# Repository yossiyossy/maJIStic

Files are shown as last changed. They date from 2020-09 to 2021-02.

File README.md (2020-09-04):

# maJIStic
Mac標準のキーボードの配列を意識した、日本語配列のキーボード

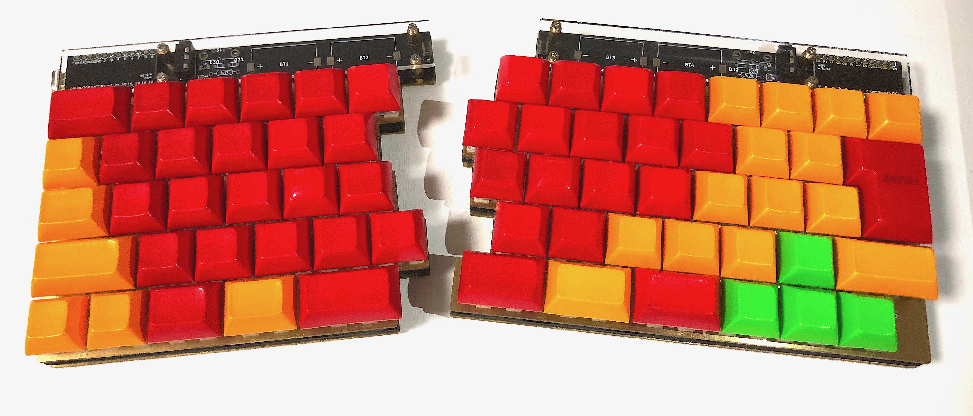
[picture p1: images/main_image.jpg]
main_image

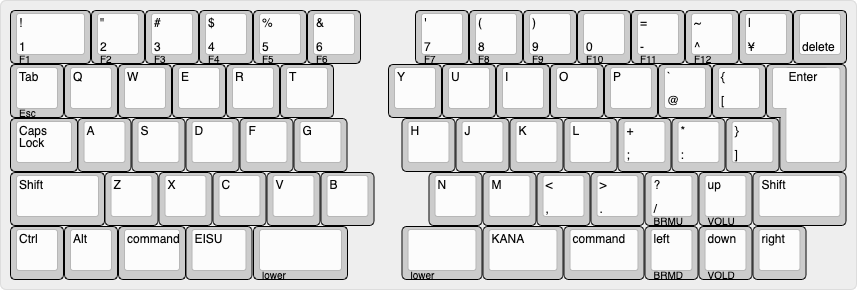
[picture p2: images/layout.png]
keyboard-layout


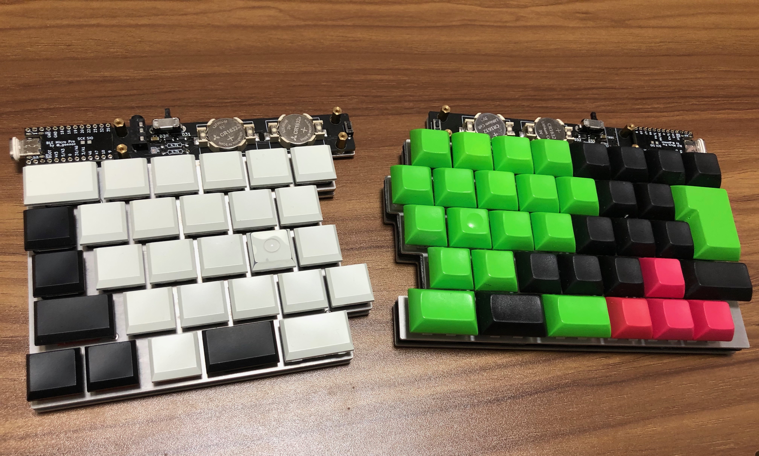
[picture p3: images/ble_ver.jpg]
ble_ver


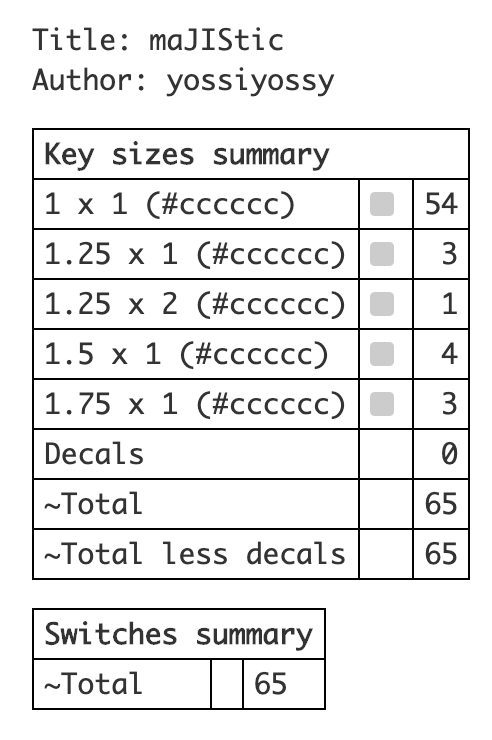
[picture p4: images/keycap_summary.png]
keycap_summary


[ビルドガイド](/docs/buildguide.md)

[特徴](/docs/feature.md)

# 買えるところ
- [booth](https://yossiyossy.booth.pm/items/2325429)

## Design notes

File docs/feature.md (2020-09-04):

# maJISticの特徴
maJISticには以下のような特徴があります
- JIS配列の左右分離型キーボード
- magic keyboard っぽい配列(1が1.5u, tabが1u, 十字キーがある)
- ソケットに対応(組み立て後にもスイッチを交換できる)
- MX, chocの両方に同時に対応させることができる
- ble micro proを使用した完全無線化に対応

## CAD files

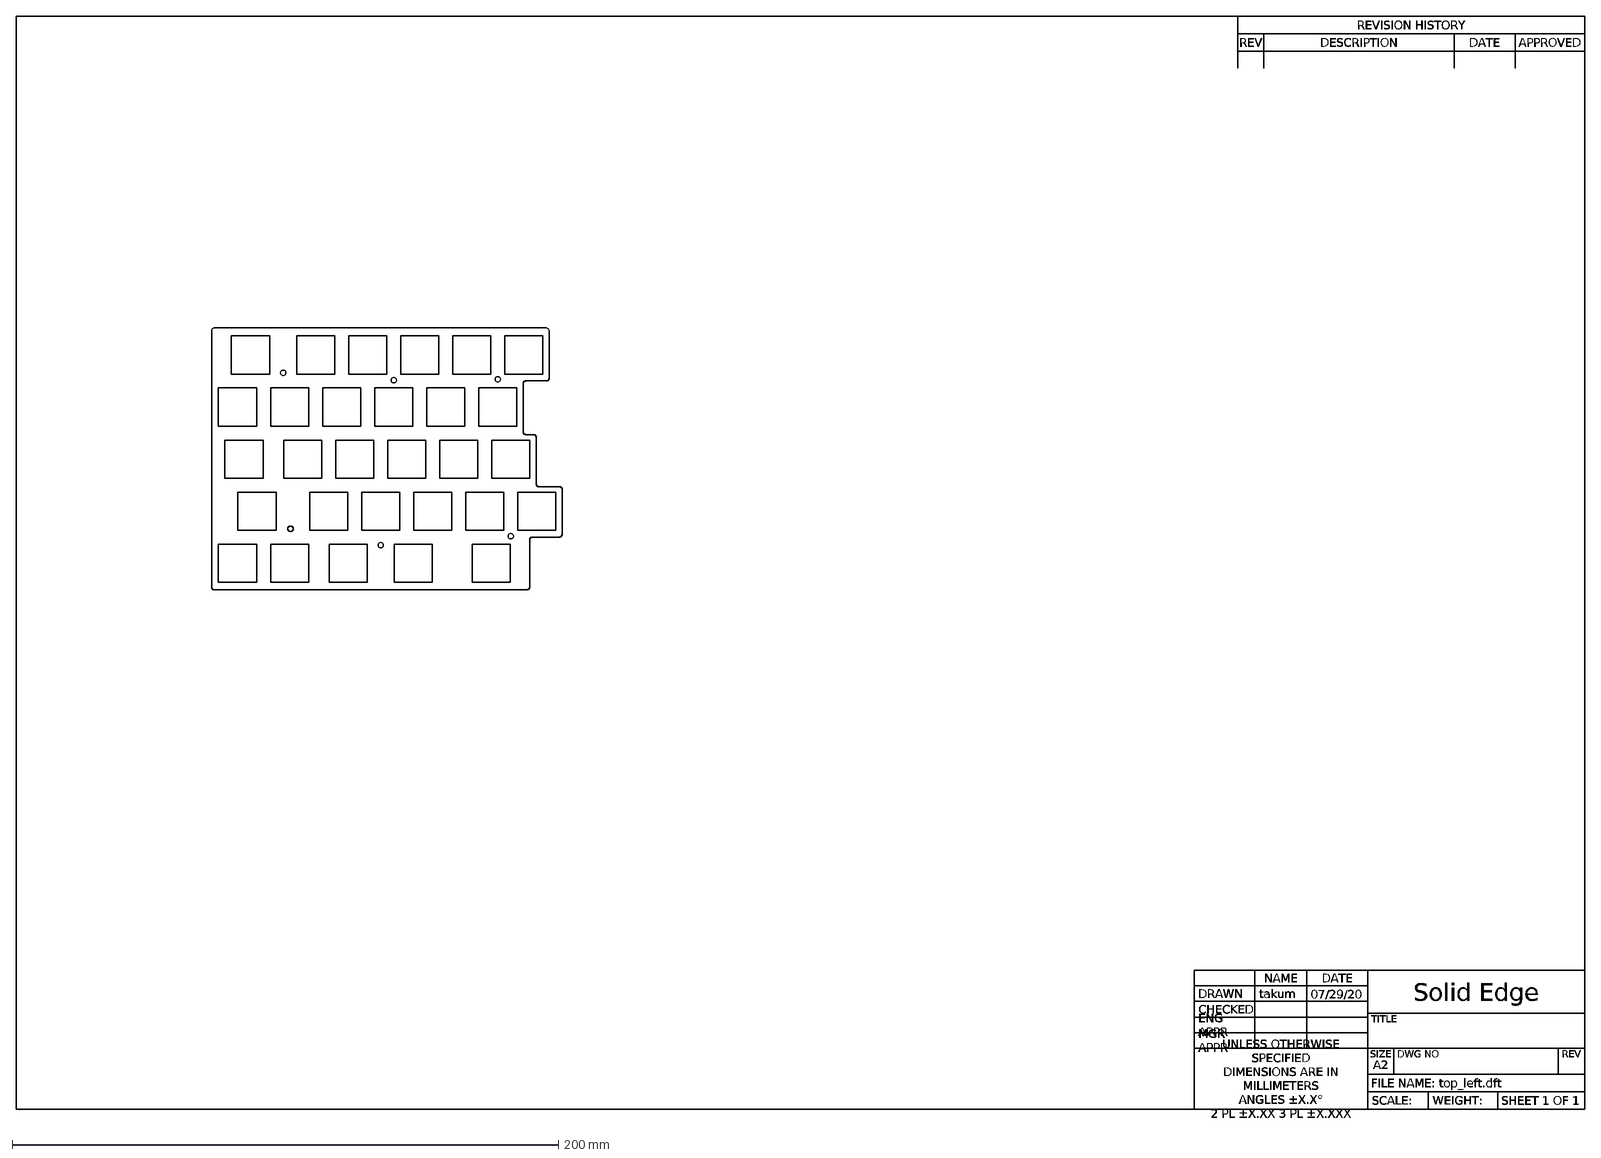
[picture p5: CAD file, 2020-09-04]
case/dxf/top_left.dxf
DRAWN
CHECKED
ENG APPR
MGR APPR
UNLESS OTHERWISE SPECIFIED DIMENSIONS ARE IN MILLIMETERS ANGLES ±X.X° 2 PL ±X.XX 3 PL ±X.XXX
NAME
takum
DATE
07/29/20
Solid Edge
TITLE
SIZE
A2
DWG NO
REV
FILE NAME: top_left.dft
SCALE:
WEIGHT:
SHEET 1 OF 1
REVISION HISTORY
DESCRIPTION
APPROVED

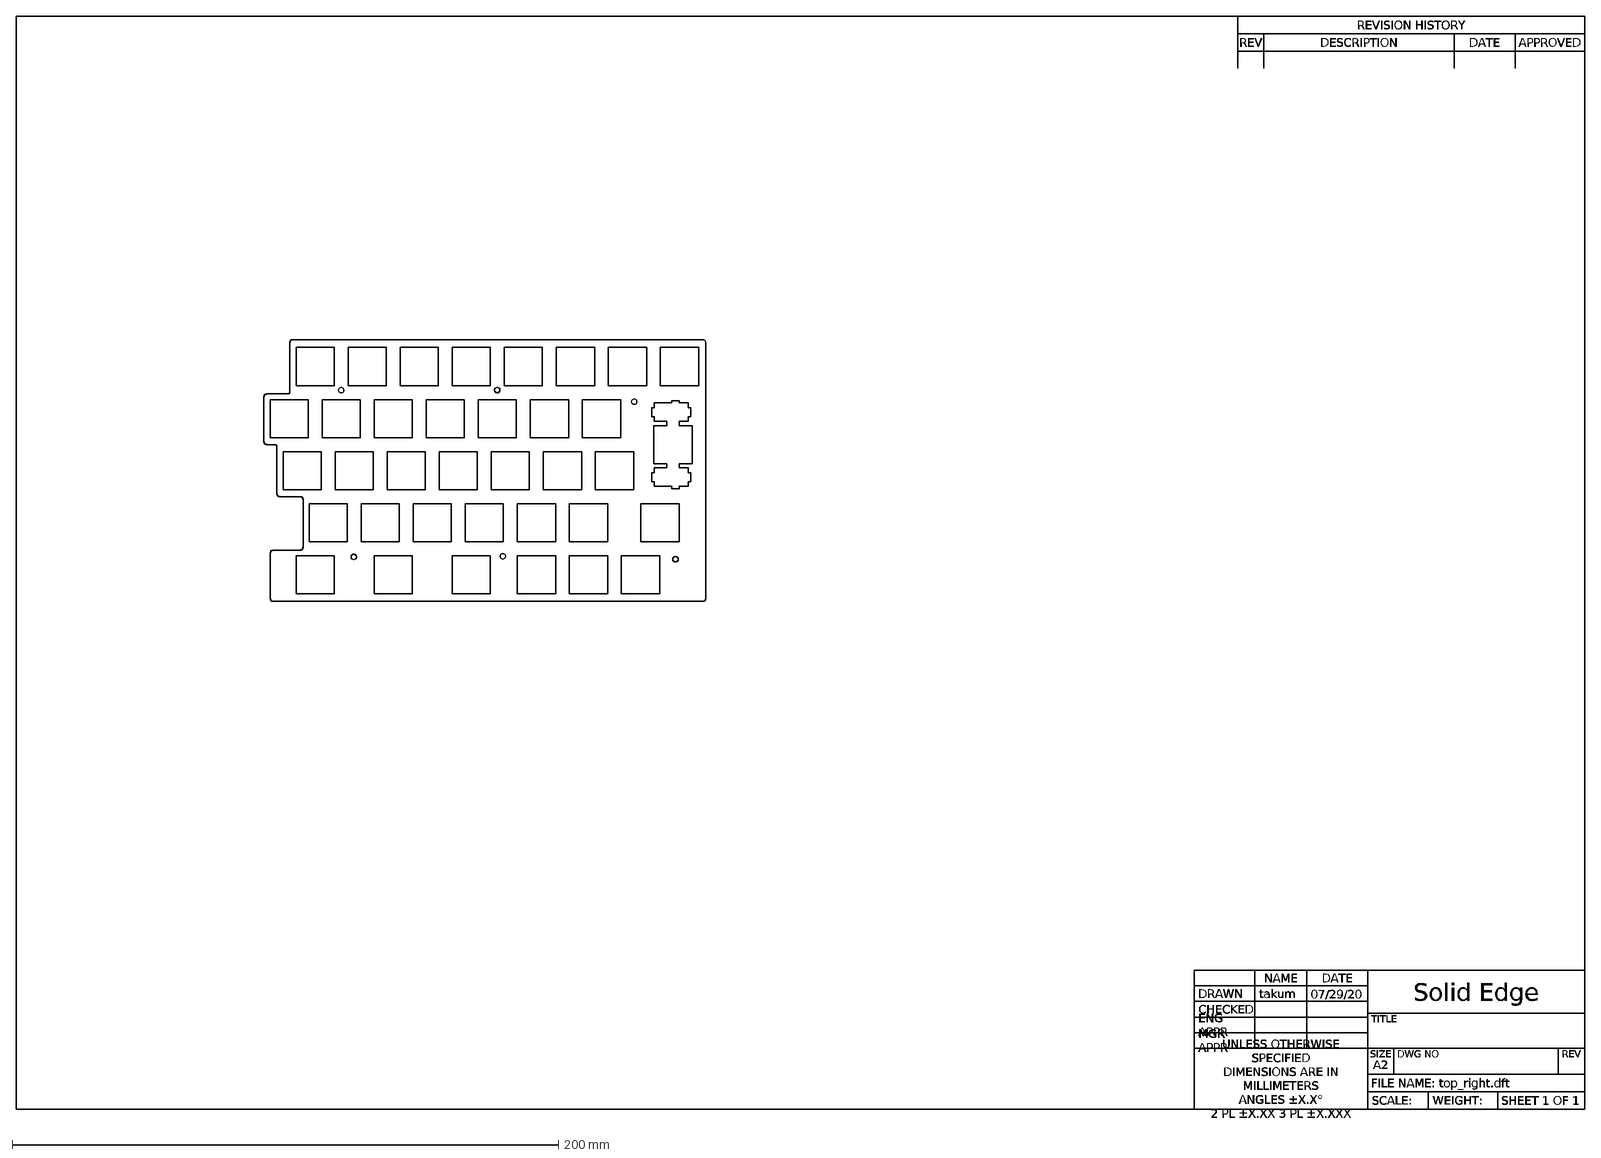
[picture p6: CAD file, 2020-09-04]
case/dxf/top_right.dxf
DRAWN
CHECKED
ENG APPR
MGR APPR
UNLESS OTHERWISE SPECIFIED DIMENSIONS ARE IN MILLIMETERS ANGLES ±X.X° 2 PL ±X.XX 3 PL ±X.XXX
NAME
takum
DATE
07/29/20
Solid Edge
TITLE
SIZE
A2
DWG NO
REV
FILE NAME: top_right.dft
SCALE:
WEIGHT:
SHEET 1 OF 1
REVISION HISTORY
DESCRIPTION
APPROVED

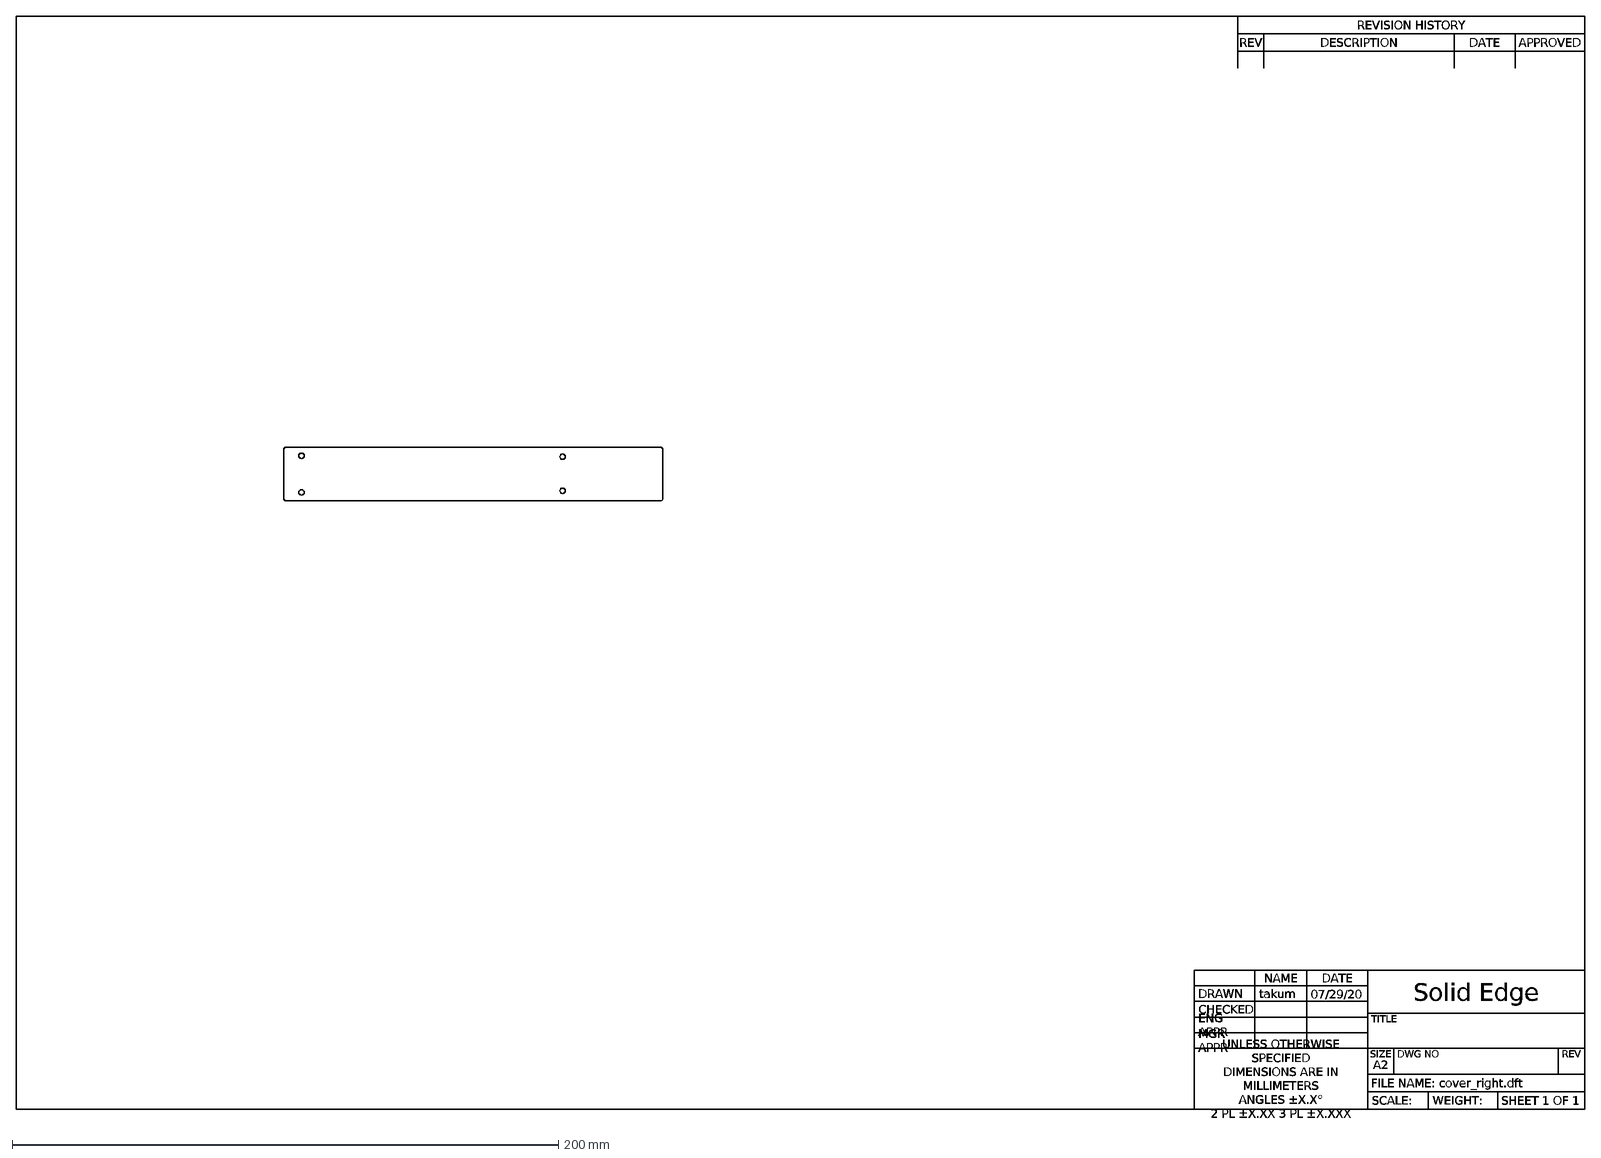
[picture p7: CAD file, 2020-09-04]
case/dxf/cover_right.dxf
DRAWN
CHECKED
ENG APPR
MGR APPR
UNLESS OTHERWISE SPECIFIED DIMENSIONS ARE IN MILLIMETERS ANGLES ±X.X° 2 PL ±X.XX 3 PL ±X.XXX
NAME
takum
DATE
07/29/20
Solid Edge
TITLE
SIZE
A2
DWG NO
REV
FILE NAME: cover_right.dft
SCALE:
WEIGHT:
SHEET 1 OF 1
REVISION HISTORY
DESCRIPTION
APPROVED

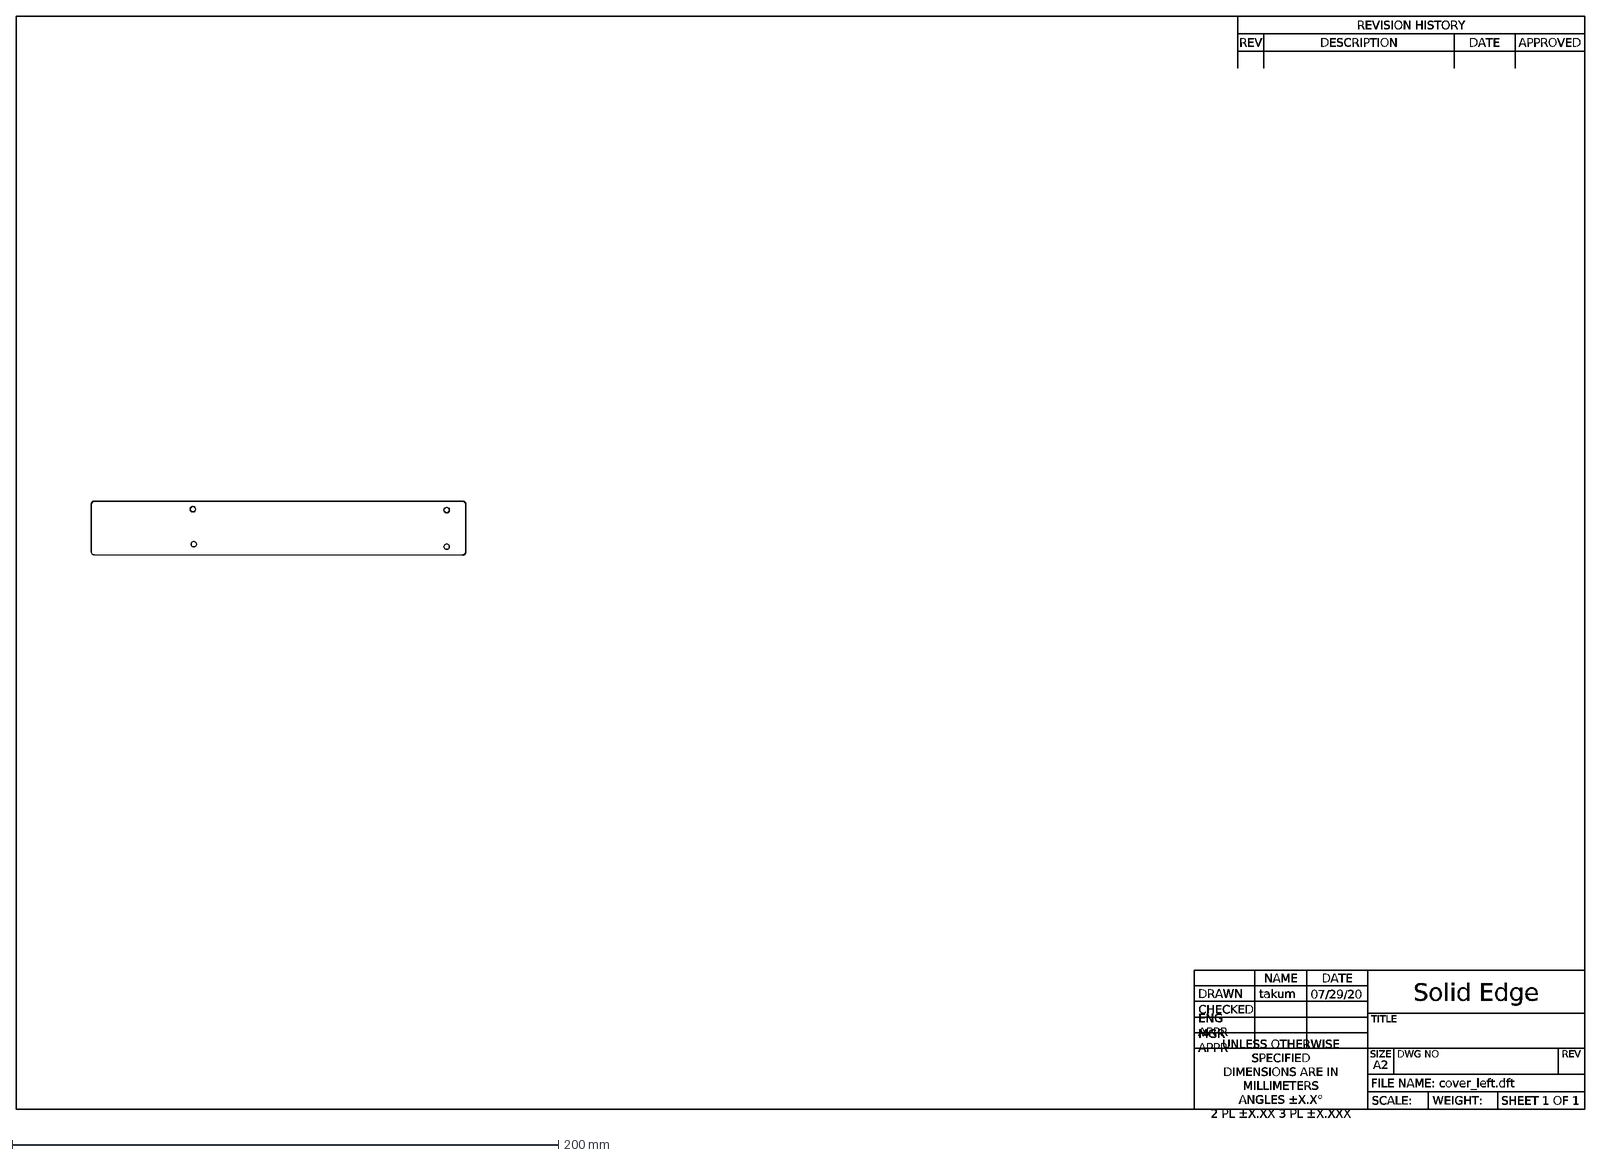
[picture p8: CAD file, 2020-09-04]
case/dxf/cover_left.dxf
DRAWN
CHECKED
ENG APPR
MGR APPR
UNLESS OTHERWISE SPECIFIED DIMENSIONS ARE IN MILLIMETERS ANGLES ±X.X° 2 PL ±X.XX 3 PL ±X.XXX
NAME
takum
DATE
07/29/20
Solid Edge
TITLE
SIZE
A2
DWG NO
REV
FILE NAME: cover_left.dft
SCALE:
WEIGHT:
SHEET 1 OF 1
REVISION HISTORY
DESCRIPTION
APPROVED

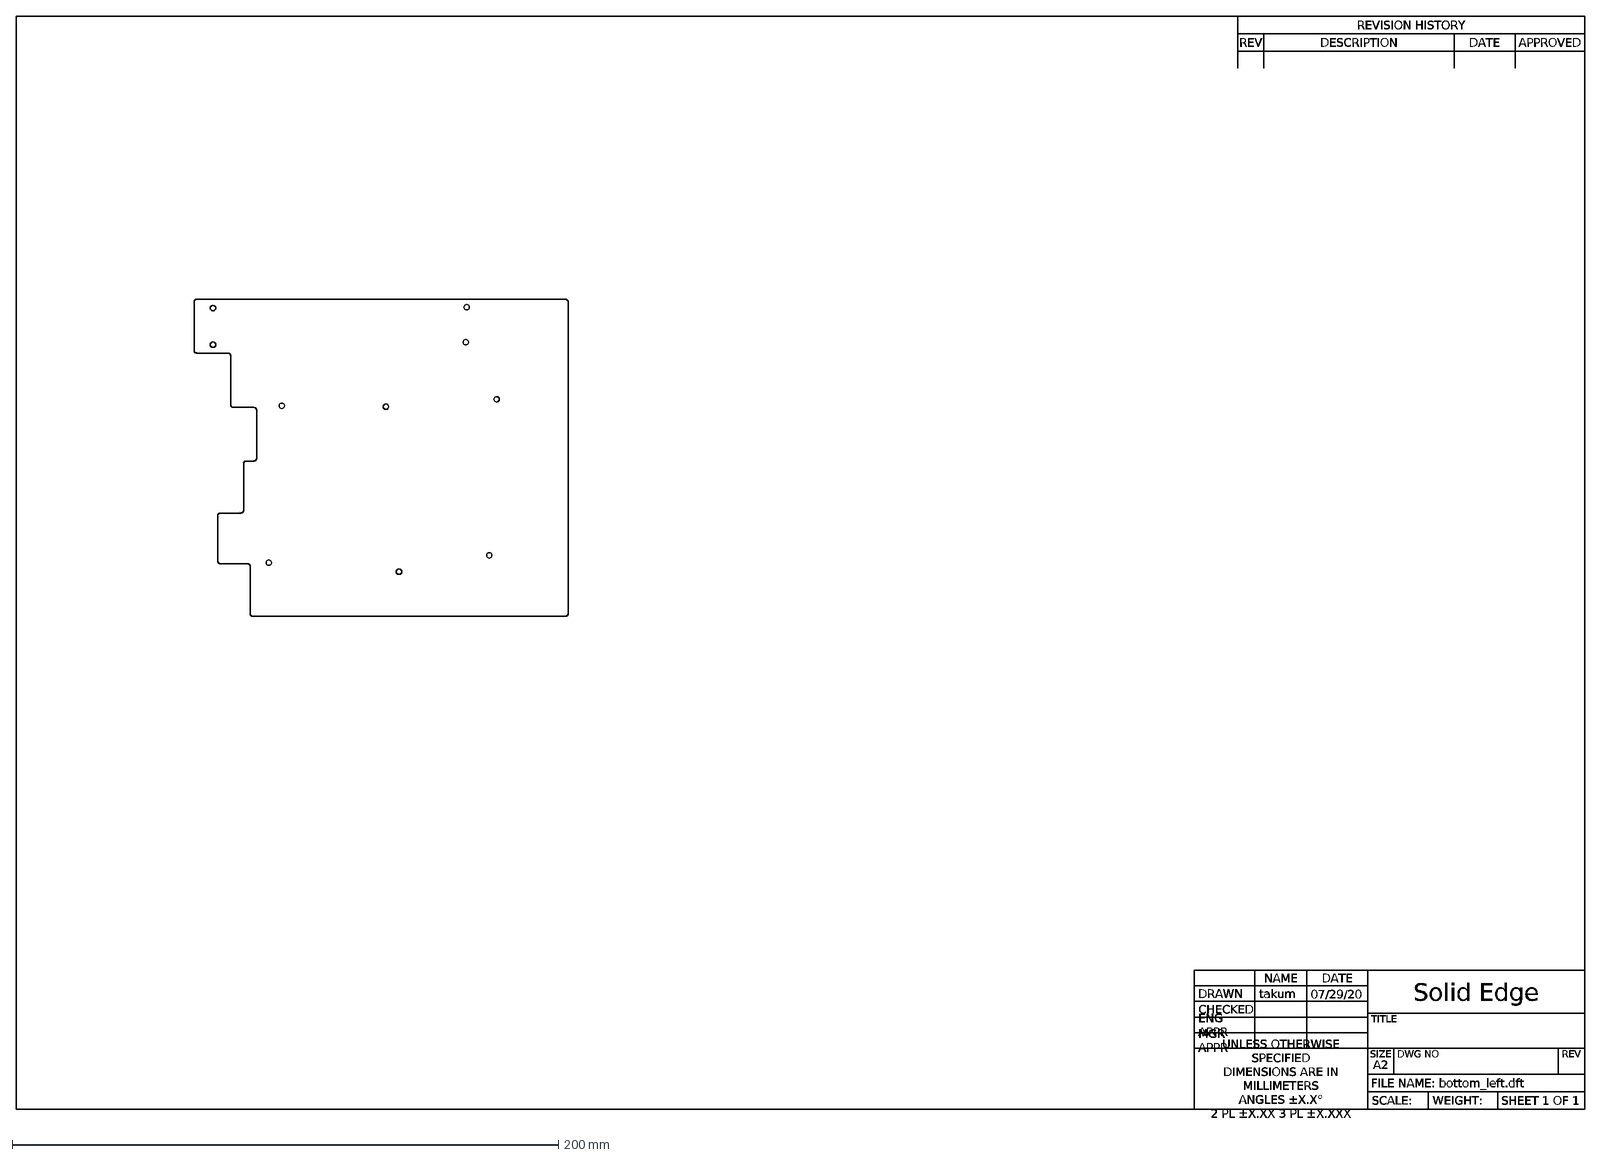
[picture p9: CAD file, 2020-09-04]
case/dxf/bottom_left.dxf
DRAWN
CHECKED
ENG APPR
MGR APPR
UNLESS OTHERWISE SPECIFIED DIMENSIONS ARE IN MILLIMETERS ANGLES ±X.X° 2 PL ±X.XX 3 PL ±X.XXX
NAME
takum
DATE
07/29/20
Solid Edge
TITLE
SIZE
A2
DWG NO
REV
FILE NAME: bottom_left.dft
SCALE:
WEIGHT:
SHEET 1 OF 1
REVISION HISTORY
DESCRIPTION
APPROVED

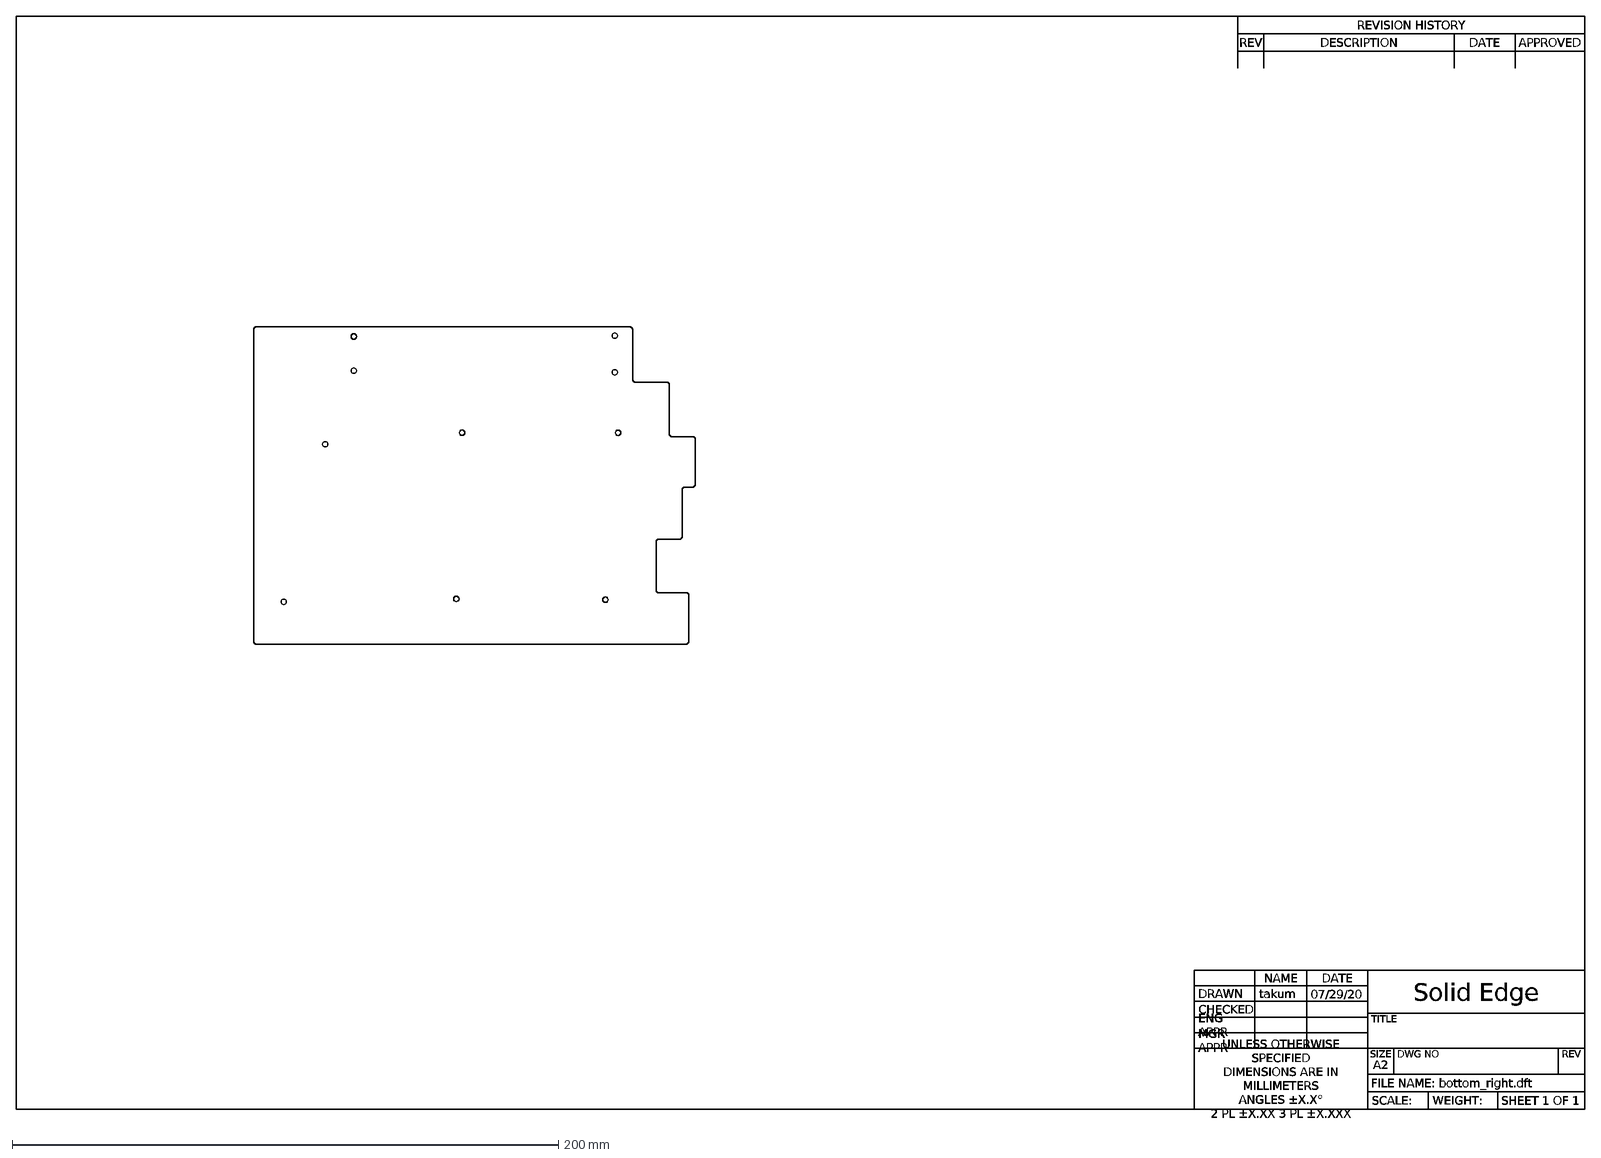
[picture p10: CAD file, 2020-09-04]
case/dxf/bottom_right.dxf
DRAWN
CHECKED
ENG APPR
MGR APPR
UNLESS OTHERWISE SPECIFIED DIMENSIONS ARE IN MILLIMETERS ANGLES ±X.X° 2 PL ±X.XX 3 PL ±X.XXX
NAME
takum
DATE
07/29/20
Solid Edge
TITLE
SIZE
A2
DWG NO
REV
FILE NAME: bottom_right.dft
SCALE:
WEIGHT:
SHEET 1 OF 1
REVISION HISTORY
DESCRIPTION
APPROVED

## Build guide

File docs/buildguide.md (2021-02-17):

# maJIStic ビルドガイド

## 部品

### 完成に必要な部品

#### よっしーのお店で買えるもの
| 名前 | 数 | 入っているセット | 備考 |
| :---- | :---- | :--- | :--- |
| PCB | 1枚 | 基板+基本パーツセット | |
| ダイオード (1N4148W) | 65個  | 基板+基本パーツセット | セットには予備として少し多めに入っています |
| TRRSジャック (MJ-4PP-9) | 2個 | 基板+基本パーツセット | |
| タクトスイッチ | 2個 | 基板+基本パーツセット | |
| ---- | ----  | --- | --- |
| スイッチ用PCBソケット(MX用) | 65個  | MX用ソケット類セット | |
| M2スペーサー 7.5mm | 12個  | MX用ソケット類セット | |
| M2ネジ 5mm | 24個  | MX用ソケット類セット | |
| ---- | ----  | --- | --- |
| スイッチ用PCBソケット(kailh choc ロープロファイル用) | 65個  | choc用ソケット類セット | |
| M2スペーサー 4mm | 12個  | choc用ソケット類セット | |
| M2ネジ 3mm | 24個  | choc用ソケット類セット | |
| ---- | ----  | --- | --- |
| トッププレート (アクリル/ アルミ/ ステンレス/ 真鍮 のいずれか) | 1組 | トッププレート | |
| ---- | ----  | --- | --- |
| ボトムプレート (アクリル/ アルミ/ ステンレス/ 真鍮 のいずれか) | 1組 | ボトムプレート | |
| ゴム足 | 8個 | ボトムプレート | |
| ---- | ----  | --- | --- |
| pro micro 保護カバー (アクリル) | 1組 | pro microカバー(アクリル) | |
| M2スペーサー 11mm | 8個 | pro microカバー(アクリル) | |
| M2ネジ 5mm | 16個  | pro microカバー(アクリル) | |

#### 他のところで買う必要のある部品
| 名前 | 数 | 備考 |
| :---- | :---- | :--- |
| Pro Micro | 2個 | |
| スプリングピンヘッダ 12P | 4個 | 通常のピンヘッダでも可 |
| 3.5mmオーディオケーブル  | 1本 | 左右のキーボード接続用 |
| micro USBケーブル | 1本 | PCとの接続用 |
| キースイッチ | 65個  | KalihロープロファイルあるいはMX互換 |
| キーキャップ | 65個  | キースイッチと互換があるもの |

### 完全無線化に必要な部品

#### よっしーのお店で買えるもの
| 名前 | 数 | 入っているセット | 備考 |
| :---- | :---- | :--- | :--- |
| コイン電池ホルダー | 4個 | 無線対応パーツセット | 注1  |
| スライドスイッチ | 2個 | 無線対応パーツセット | 注1  |
| コンデンサ | 2個 | 無線対応パーツセット | 注1  |
| ショットキーバリアダイオード | 4個 | 無線対応パーツセット | 注1  |

注1: セット1つには片手分の部品しか入っていません。完全無線化する場合はセットを2つ購入していただく必要があります。

#### 他のところで買う必要のある部品
| 名前 | 数 | 備考 |
| :---- | :---- | :--- |
| BLE Micro Pro | 2個 | Pro Microと置き換えて使用します |
| スプリングピンヘッダ 13P | 4個 | 通常のピンヘッダでも可 |
| 1632型コイン電池 | 4個 | |
| ポリウレタン銅線 | | 無線化時に短絡させる必要のある箇所を繋ぐのに使用します |

## 必要な道具

| 名前 | 備考 |
| :---- | :---- |
| はんだごて | |
| ハンダ | 0.8mm程度のものを推奨 |
| ピンセット | 表面実装部品の半田付けに使用 |

## 組み立て方

以降は左手分だけの説明を書きます。
右手分は左手分と同様に作業してください。

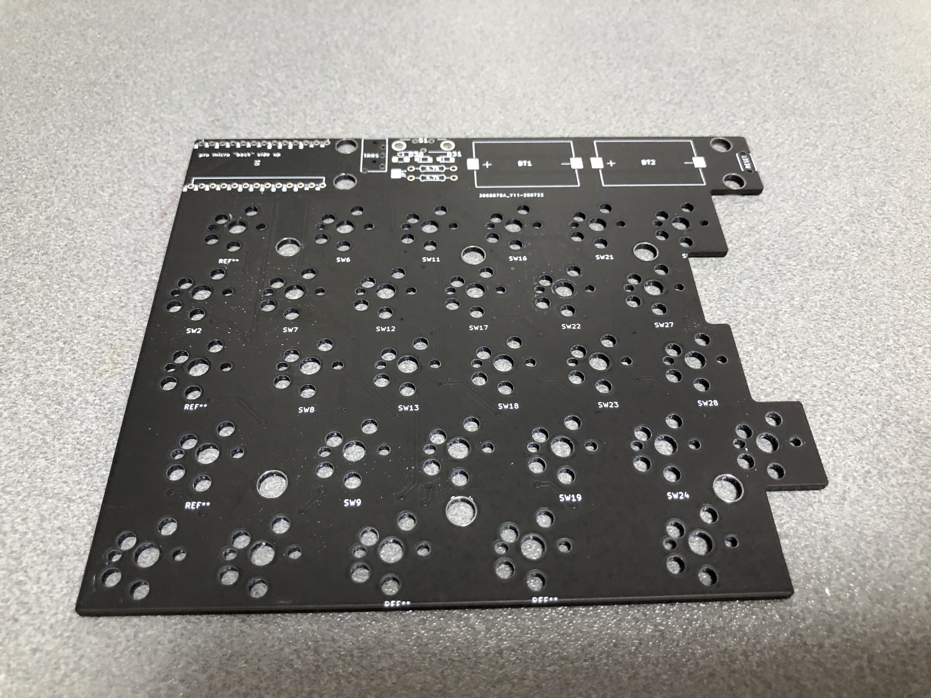
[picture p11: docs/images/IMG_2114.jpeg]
左手分のPCB


__一度全ての工程を読み、理解してから作業を進めることをお勧めします。__

### クリアラッカーの散布 (金属製ケースの場合)
~~maJISticの金属製ケースは、表面に特殊な処理をを行っておりません。~~
~~そのため、手汗などが付着するとくすみの原因になってしまいます。~~

~~事前に以下のようなクリアラッカー等で表面を保護することをおすすめします。~~

金属製ケースを製造していただいた切断堂様にて、クリアコートをしていただくようになったため、
今後発送する商品に関しては、特に下準備は必要なくなりました。(2021/02追記)

### PCBの準備 (部分無線化する場合)
オプションの**LPME-IOを使用した部分無線化を行う場合のみ**、以下の処理が必要です(左右両方の基盤に対して行う必要があります)
- カッターなどで以下のジャンパを切断する。
- 以下の箇所をポリウレタン銅線などでショートさせる

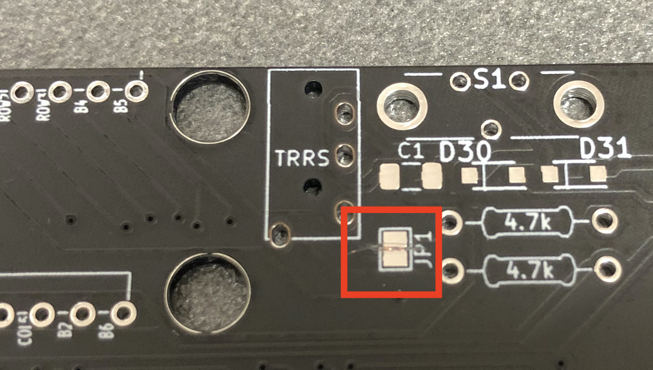
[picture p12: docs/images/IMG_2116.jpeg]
切るジャンパの画像


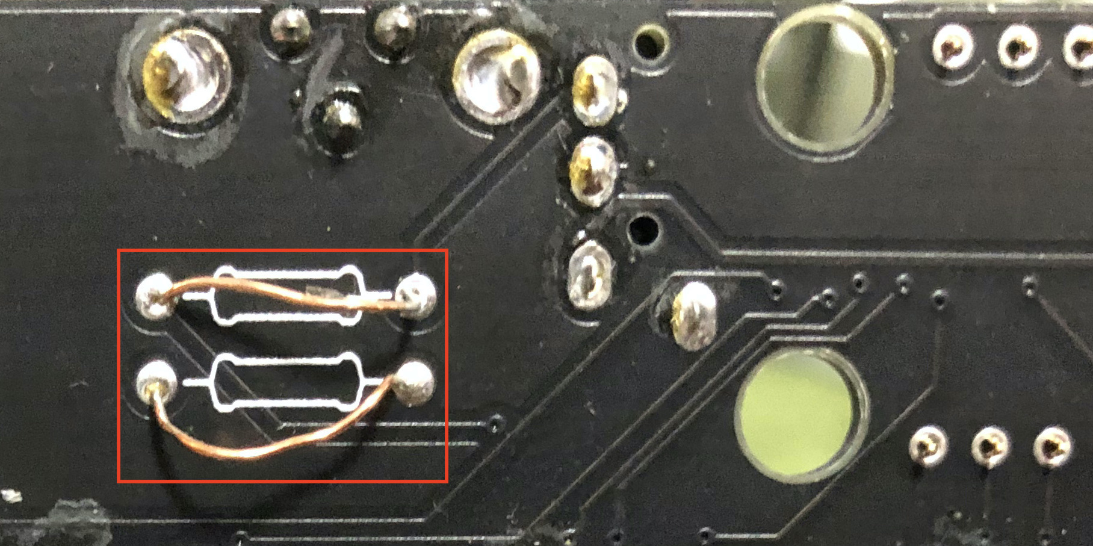
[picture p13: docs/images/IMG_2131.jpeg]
繋いだ画像


### パーツ実装

#### 無線化用パーツ
完全無線化する場合は左右両方に、部分無線化する場合は左手側に、無線化用パーツを取り付けます。

無線化に用いる部品は、それぞれがかなり小さいため、先に取り付けることをおすすめします。
特にTRRSジャックをつけた後に実装するのはかなり難しいため(体験談)、遅くともそこまでに取り付けてください。

コンデンサは向きがありませんが、ショットキーバリアダイオードは向きがあります。
かなりわかりにくかとは思いますが、シルクを見て取り付けてください。

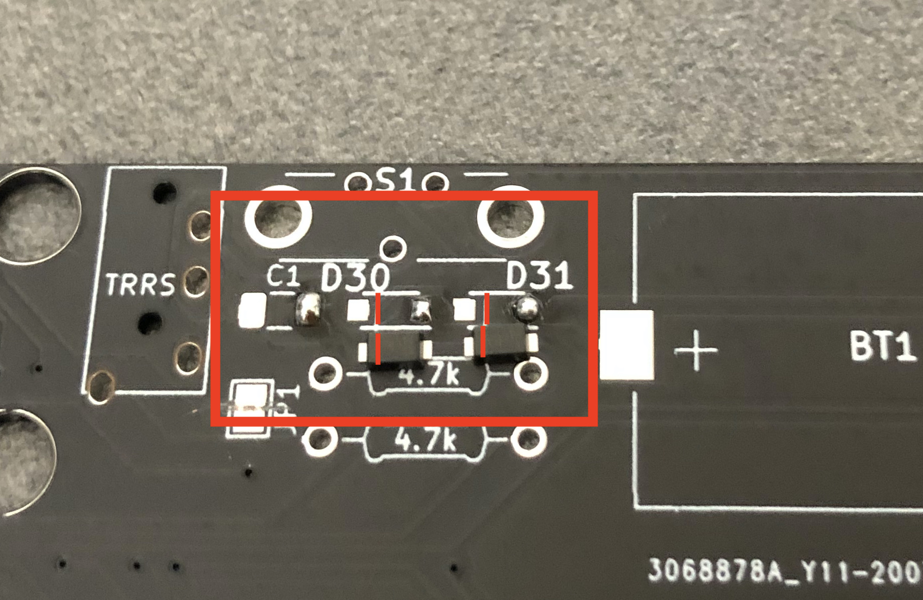
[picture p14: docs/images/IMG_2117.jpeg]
ショットキーバリアダイオードの付け方の画像


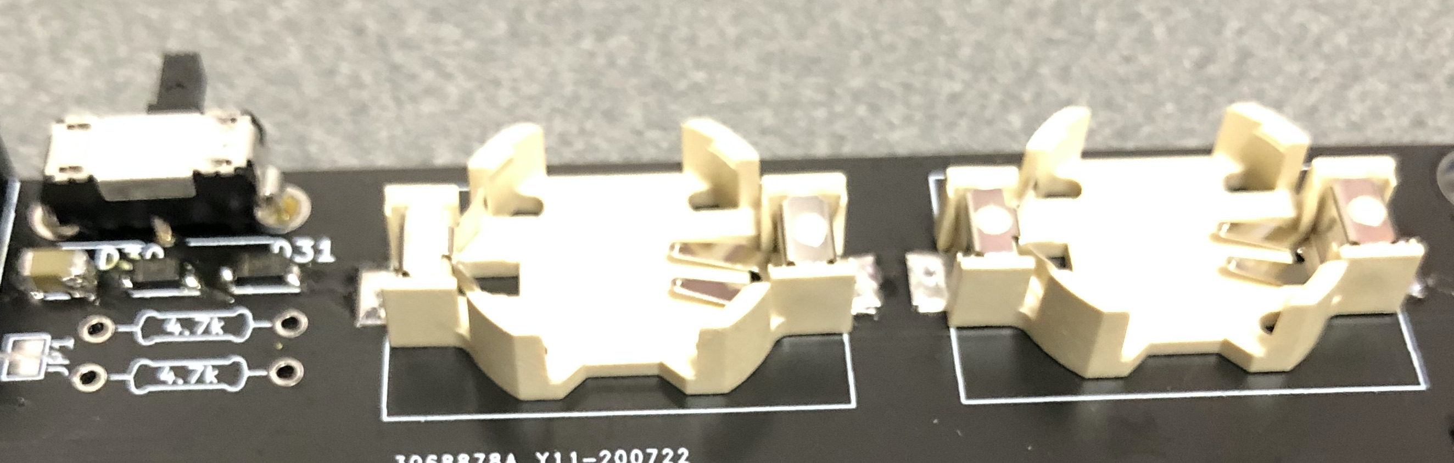
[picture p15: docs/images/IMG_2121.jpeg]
無線化用パーツを取り付けた姿の画像


#### ダイオード

ダイオードには向きがあるので注意してください。
シルクが見えなくなっているところがありますが、全て同じ方向なので他に合わせてください。

矢印が向いてる先に線の付いてる側を合わせます。

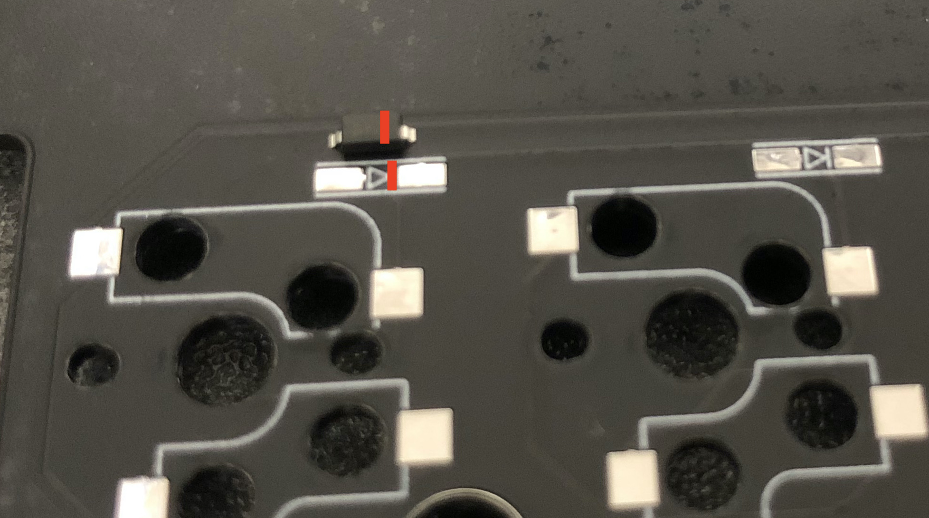
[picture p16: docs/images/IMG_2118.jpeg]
ダイオードの画像


#### スイッチ用ソケット

MX用とchoc用は形状が異なるため、ハンダ付けする箇所が異なります。
予備ハンダをする際は、自分が使うタイプのソケット用のパッドであることをご確認の上、行ってください。

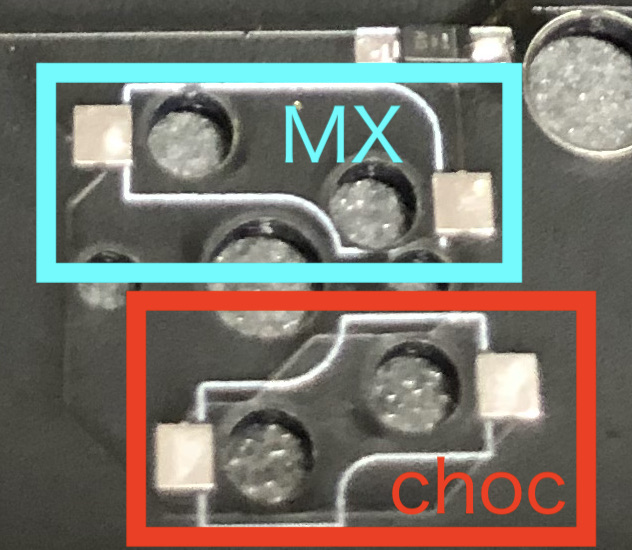
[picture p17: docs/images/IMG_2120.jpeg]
ソケットの画像


#### TRRSジャック

TRRSジャックを上面から実装してください。

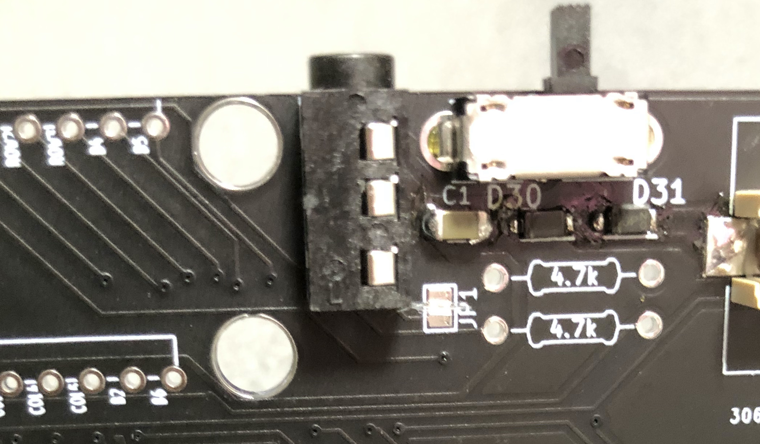
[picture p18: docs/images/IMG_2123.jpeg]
TRRSジャックの画像


#### リセットスイッチ

タクトスイッチを上面から実装してください。

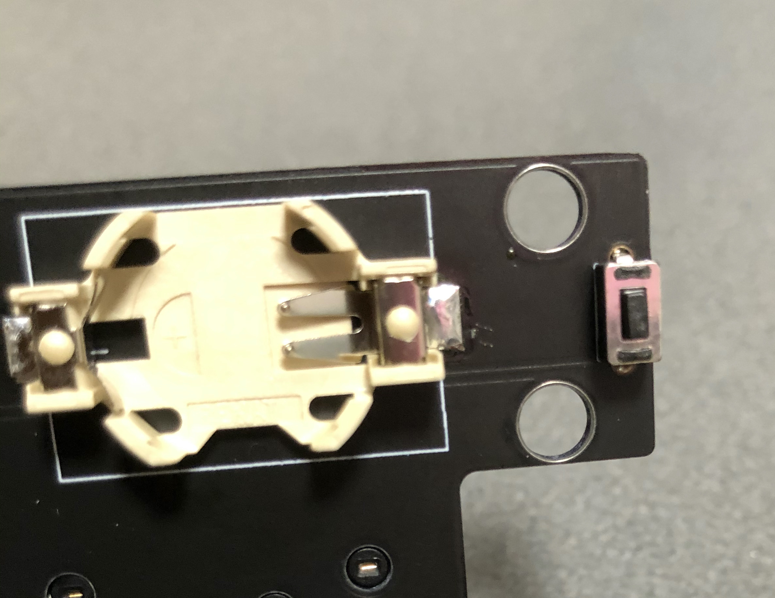
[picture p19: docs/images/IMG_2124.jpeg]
タクトスイッチの画像


#### Pro Micro

スプリングピンヘッダをPro Microに半田付けします。Pro Microの裏面（平らな方）が上になるようにします。

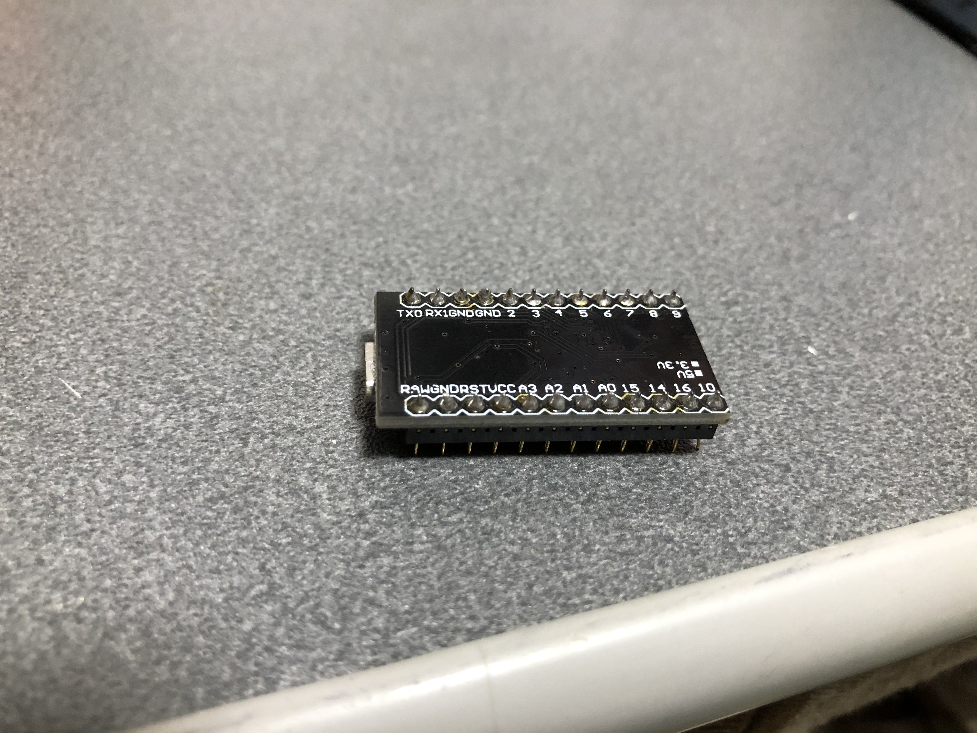
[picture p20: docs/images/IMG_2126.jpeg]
Pro Microの向きの画像


スプリングピンヘッダには推奨する向きがあります。

小さい窓がPro Micro寄りになります。
また、実装時には二本ともに小さい窓が同じ方向を向くようにしてください。

(かなり見えづらい上にピンが一本曲がってますが、ご容赦ください……)

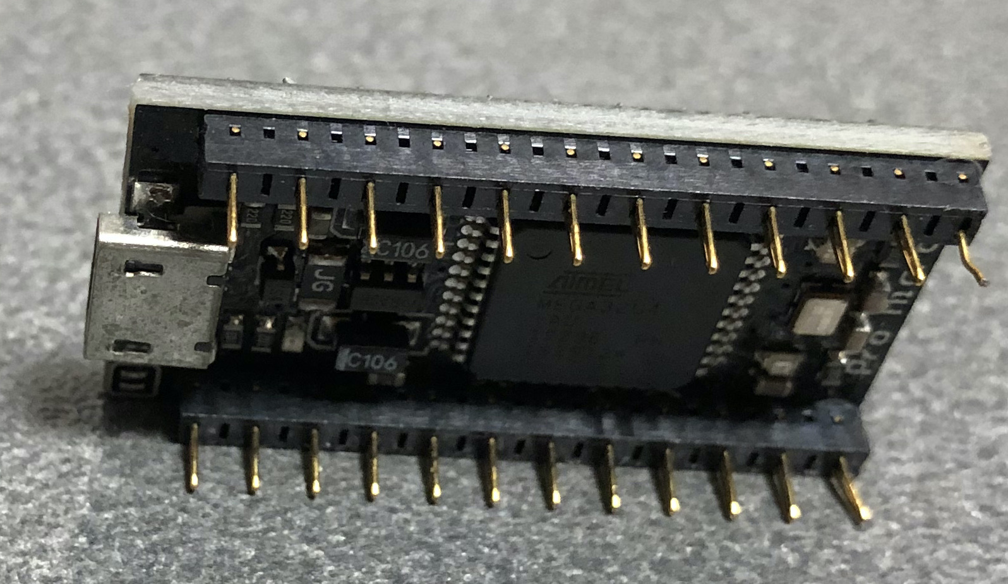
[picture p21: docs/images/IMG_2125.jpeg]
コンスルーの説明


※向きを間違えたり、はんだ付けする前に強い力がかかるとピンが外れますので注意してください。また、足が折れ曲りやすいので抜き差しするときには注意して扱ってください。

裏面を上にしてPCBの白枠線内のスルーホールに取り付けてください。はんだ付けしなくても固定されます。
一番外側のスルーホールはBLE Micro Pro用のものですので、通常のPro Microを使用する場合はそこにかからない用に取り付けてください。

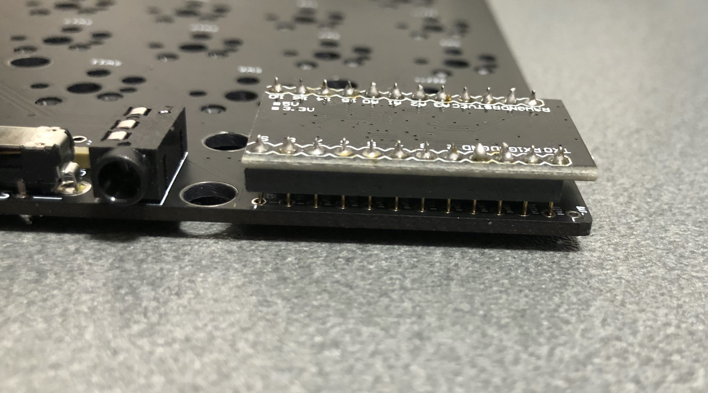
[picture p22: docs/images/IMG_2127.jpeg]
ProMicroの画像


#### キースイッチ

キースイッチを、トッププレートを挟んでpcbのソケットに嵌めます。
(以下の画像ではネジがついていますが、本来この時点ではネジは不要です)

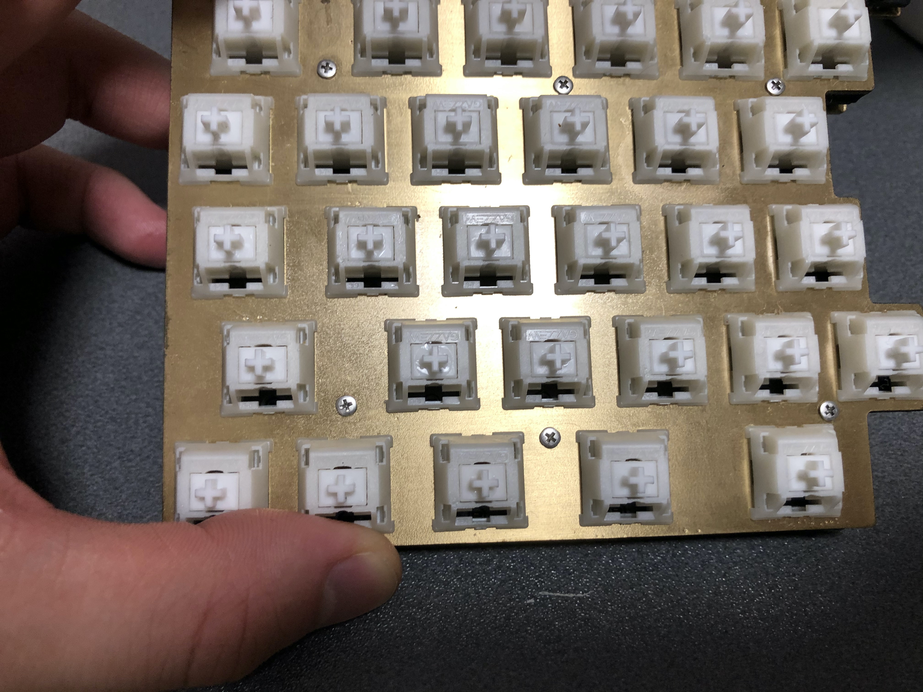
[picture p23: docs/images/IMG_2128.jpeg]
スイッチの付け方


※ここで一旦[ファームウェア](https://github.com/qmk/qmk_firmware/tree/master/keyboards/majistic)を書き込み、動作確認をすることを推奨します。

### 最終組み立て

choc(ロープロスイッチ)は4mm、MXキースイッチは7.5mmのスペーサーを使ってPCBを挟むようにボトムプレートをネジ止めし、ゴム足を底面に貼ります。

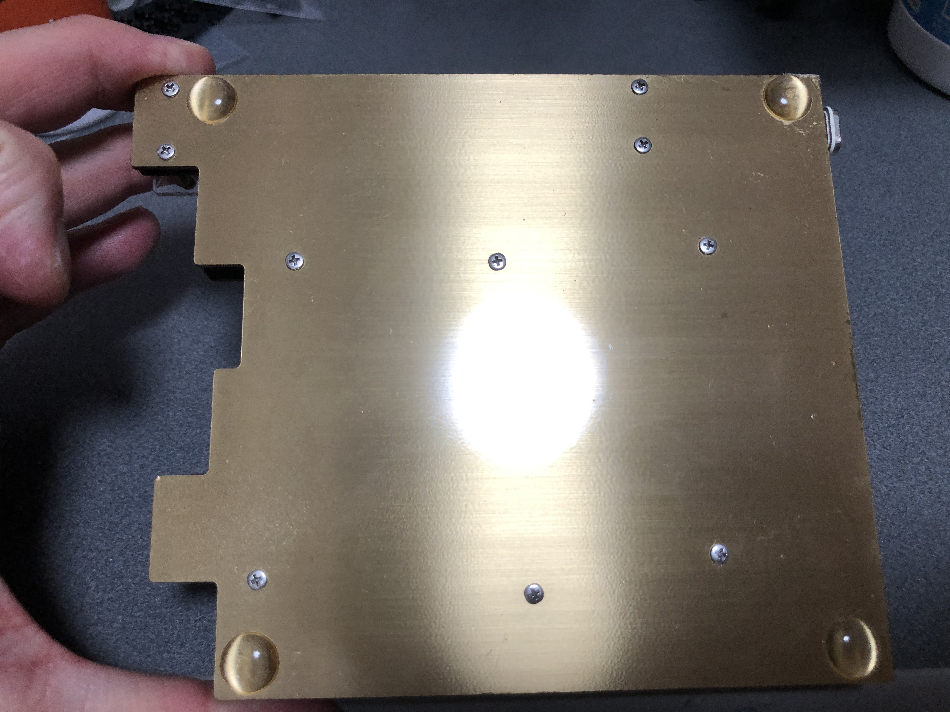
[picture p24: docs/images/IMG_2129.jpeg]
ボトムプレートの画像


保護カバーを11mmのスペーサーと5mmのネジを使ってネジ止めします。

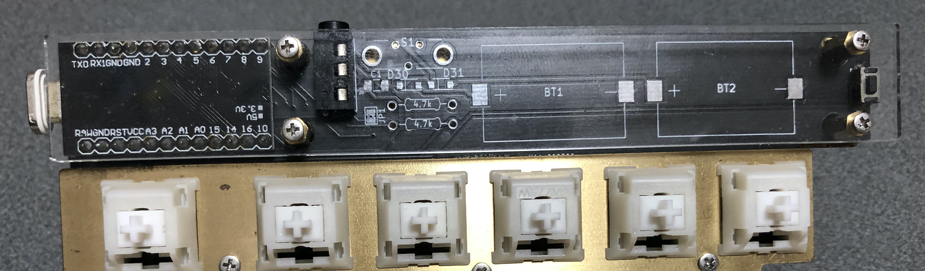
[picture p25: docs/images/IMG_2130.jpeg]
保護カバーの画像


完成です。

完成形の画像

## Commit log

2020-09-04 add case data
    [bottom_left.dxf, bottom_right.dxf, cover_left.dxf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]
2020-09-04 add pcb
2021-02-17 fix wireless
